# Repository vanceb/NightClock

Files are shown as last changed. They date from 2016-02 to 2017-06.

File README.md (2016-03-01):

# NightClock
This was my first project after joining the [Reading Hackspace](http://rlab.org.uk/).  It exposed me to a number of new techniques and software.

* 2D CAD and laser cutting for the physical clock.  CAD models in dxf format and some cutting files from RDWorks (used by the hackspace laser cutter) are included in the cad folder.
* PCB Design using [Kicad](http://kicad-pcb.org/).  This is the first PCB I have designed.  I had it made in China by [PCBWay](http://www.pcbway.com/).
* Programming the ESP8266 and neopixels for the clock electronics.  I used [Platformio](http://platformio.org/) to program the ESP8266 and manage the libraries.  It uses the core Arduino model for software development, but I prefer it to using the Arduino IDE, which I find frustrating.  I have also used the platformio-ide plugin for [Atom](https://atom.io/), which also works well.

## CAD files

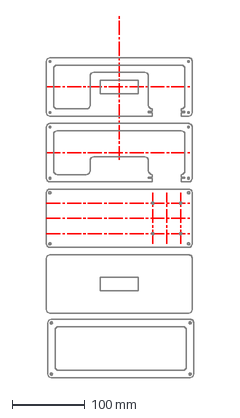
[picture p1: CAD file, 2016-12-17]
cad/NewBase_Wood.dxf
202.0 x 495.3 mm

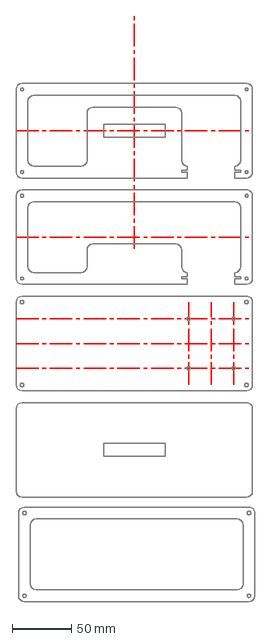
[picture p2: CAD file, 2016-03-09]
cad/NewBase.dxf
202.0 x 495.3 mm

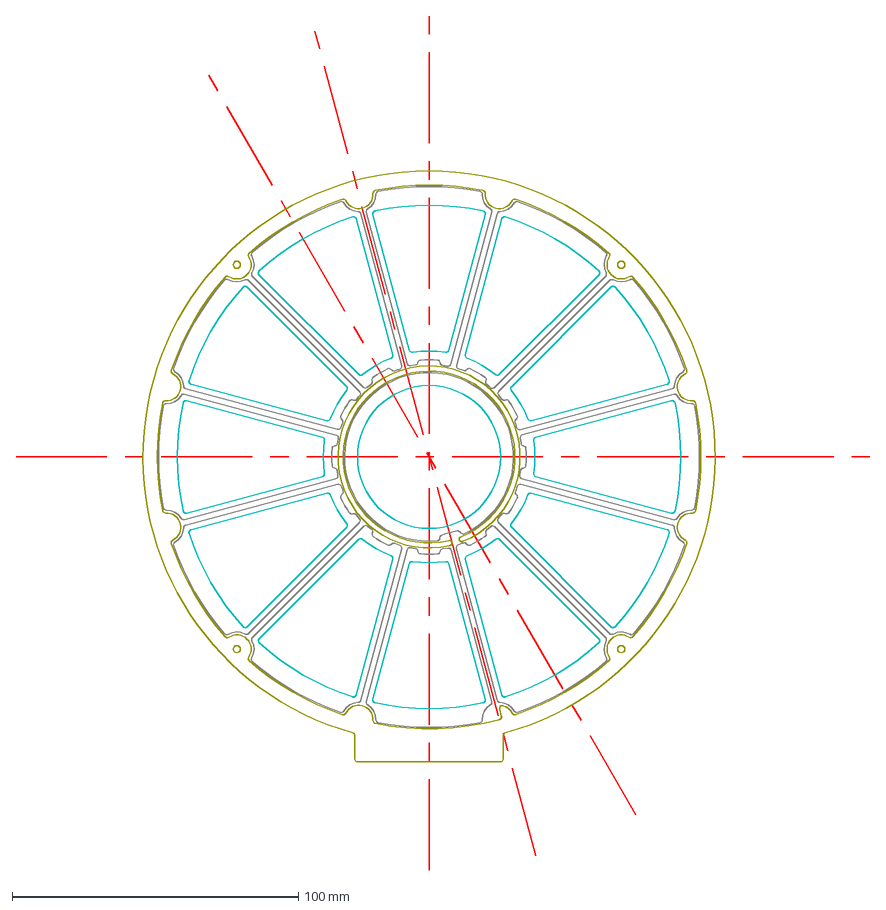
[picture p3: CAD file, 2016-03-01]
cad/Clock.dxf
298.5 x 298.5 mm

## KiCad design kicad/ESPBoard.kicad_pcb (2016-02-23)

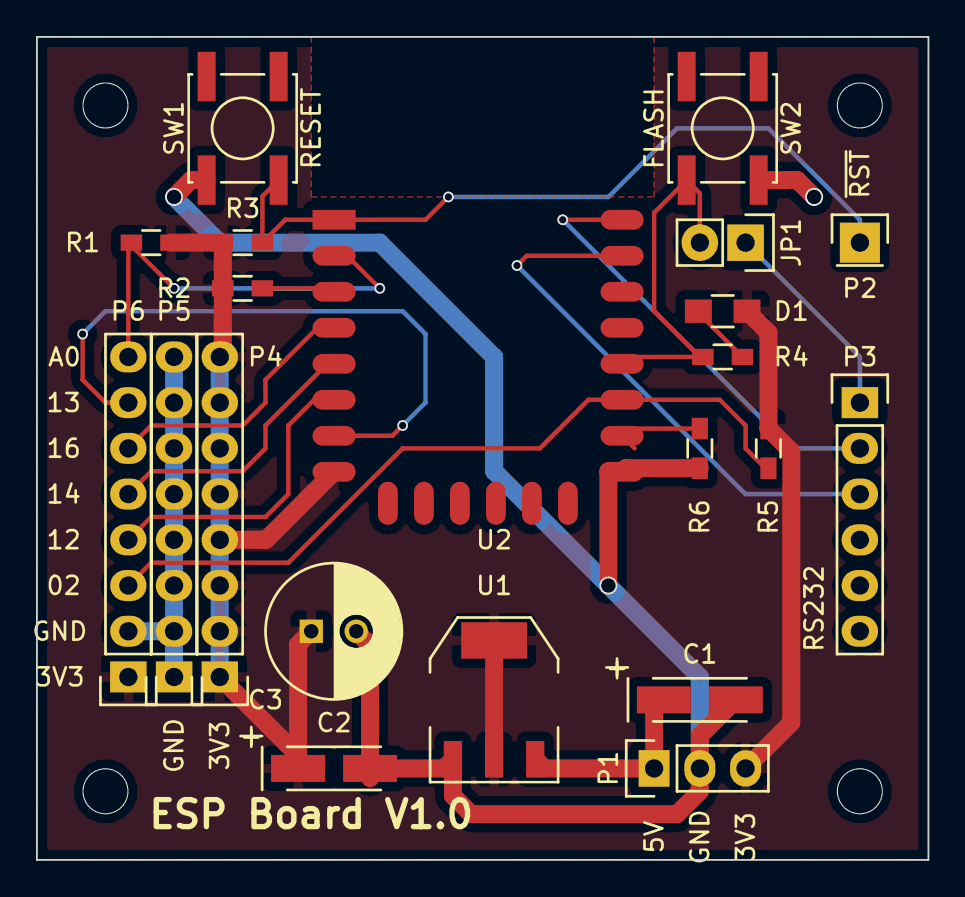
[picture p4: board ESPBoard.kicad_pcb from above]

Board: 2 copper layers, 49.5 x 45.7 mm, 21 parts (0 on the bottom side), 17 nets.

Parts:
C1, C2: 10u; TantalC_SizeA_EIA-3216_HandSoldering
C3: 1000u; C_Radial_D7.5_L11.2_P2.5
D1: LED; R_0805_HandSoldering
JP1: AUTO_FLASH; Pin_Header_Straight_1x02
P1: PWR; Pin_Header_Straight_1x03
P2: EXT_RESET; Pin_Header_Straight_1x01
P3: RS232; Pin_Header_Straight_1x06
P4: 3.3V; Pin_Header_Straight_1x08
P5: Gnd; Pin_Header_Straight_1x08
P6: GPIO; Pin_Header_Straight_1x08
R1: 470k; R_0603_HandSoldering
R2, R3, R5, R6: 10k; R_0603_HandSoldering
R4: 330R; R_0603_HandSoldering
SW1: RESET; SW_SPST_EVPBF
SW2: FLASH; SW_SPST_EVPBF
U1: LM1117-3.3; SOT-223
U2: ESP-12E

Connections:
+3V3: C2.1, C3.1, D1.2, P1.3, P4.1, P4.2, P4.3, P4.4, P4.5, P4.6, P4.7, P4.8, P6.1, R1.1, R2.1, R3.1, R5.1, U1.2, U1.4, U2.8
+5V: C1.1, P1.1, U1.3
/ESP_ADC: P6.8, R1.2, U2.2
/ESP_CH_PD: R2.2, U2.3
/ESP_GPIO0: JP1.2, R4.2, SW2.2, U2.18
/ESP_GPIO2: P6.3, R5.2, U2.17
/ESP_GPIO12: P6.4, U2.6
/ESP_GPIO13: P6.7, U2.7
/ESP_GPIO14: P6.5, U2.5
/ESP_GPIO15: R6.1, U2.16
/ESP_GPIO16: P6.6, U2.4
/ESP_RESET: P2.1, R3.2, SW1.2, U2.1
/ESP_RX_IN: P3.3, U2.21
/ESP_TX_OUT: P3.2, U2.22
/SERIAL_DTR: JP1.1, P3.1
GNDPWR: C1.2, C2.2, C3.2, P1.2, P3.6, P5.1, P5.2, P5.3, P5.4, P5.5, P5.6, P5.7, P5.8, P6.2, R6.2, SW1.1, SW2.1, U1.1, U2.15
unnamed: D1.1, R4.1

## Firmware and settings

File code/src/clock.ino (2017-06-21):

// https://github.com/adafruit/Adafruit_NeoPixel
// Platformio lib number 28
#include <Adafruit_NeoPixel.h>

// https://github.com/PaulStoffregen/Time
// Platformio lib number 28
#include <TimeLib.h>

// Time zone and daylight savings conversion, but cannot be used as-is
// ESP eeprom library not yet ported, so edited library to remove
// requirement on that library
// Original Library
// https://github.com/JChristensen/Timezone
// If it worked OOTB then would be Platformio lib number 76
// Forked version
// https://github.com/vanceb/Timezone
#include <Timezone.h>

// https://github.com/esp8266/arduino
#include <ESP8266WiFi.h>
#include <WiFiUdp.h>

// Use WifiManager to allow easier setting of Wifi
#include <DNSServer.h>
#include <ESP8266WebServer.h>
#include <WiFiManager.h>

// Enable OTA Software updates
#include <ESP8266mDNS.h>
#include <ArduinoOTA.h>

// Define the parameters for the neopixels
#define NEO_PIN 13
#define NEO_NUMPIXELS 13

// Enum and variable to hold the status
enum status {WIFI_UP, WIFI_DOWN, WIFI_CFG, NTP_FAIL};
status clock_status = WIFI_DOWN;

// NTP Servers:
IPAddress timeServerIP; // time.nist.gov NTP server address
const char* ntpServerName = "1.uk.pool.ntp.org";
//IPAddress timeServer(132, 163, 4, 101); // time-a.timefreq.bldrdoc.gov
// IPAddress timeServer(132, 163, 4, 102); // time-b.timefreq.bldrdoc.gov
// IPAddress timeServer(132, 163, 4, 103); // time-c.timefreq.bldrdoc.gov

// Setup timezone and daylight saving correction library
TimeChangeRule ukGMT = {"GMT", Last, Sun, Oct, 2, 0};
TimeChangeRule ukBST = {"BST", Last, Sun, Mar, 2, 60};
Timezone ukTZ(ukGMT, ukBST);

// Create the Neopixel object
Adafruit_NeoPixel strip = Adafruit_NeoPixel(NEO_NUMPIXELS, NEO_PIN, NEO_GRB + NEO_KHZ800);

// To allow for OTA reconfig of colours later on define a set of variables
uint32_t col_wifi_down = strip.Color(128,0,0);
uint32_t col_wifi_up = strip.Color(0,128,0);
uint32_t col_wifi_cfg = strip.Color(0,0,128);
uint32_t col_ntp_fail = strip.Color(64,64,0);
uint32_t col_hours = strip.Color(255,0,0);
uint32_t col_minutes = strip.Color(0,0,255);
uint32_t col_seconds = strip.Color(0,255,0);
uint32_t col_background = strip.Color(0,0,0);

uint8_t show_sec_brightness = 64;
uint8_t min_brightness = 3;
uint8_t max_brightness = 255;
uint32_t last_updated = millis();
uint32_t time_now = millis();
uint8_t disp_update_period = 40;
uint8_t ntp_sync_interval = 3600;

// Manage brightness with hysteresis
#define GO_BRIGHT 600
#define GO_DARK 700
bool isDark = false;

// Some status variables
bool ntp_fail = false;
bool wifi_cfg = false;

// Create the UDP object
WiFiUDP Udp;

unsigned int localPort = 8888;  // local port to listen for UDP packets


void walk(uint32_t c, uint8_t wait){
    for(int i=0; i < strip.numPixels(); i++){
        strip.setPixelColor(i, c);
        strip.show();
        delay(wait);
        strip.setPixelColor(i, 0);
    }
}

void showStatus(){
    if (wifi_cfg) {
        clock_status = WIFI_CFG;
        strip.setPixelColor(12, col_wifi_cfg);
    } else {
        switch (WiFi.status()){
            case WL_CONNECTED :
            if(ntp_fail) {
                clock_status = NTP_FAIL;
                strip.setPixelColor(12, col_ntp_fail);
            } else {
                clock_status = WIFI_UP;
                strip.setPixelColor(12, col_wifi_up);
            }
            break;
            default :
            strip.setPixelColor(12, col_wifi_down);
            clock_status = WIFI_DOWN;
        }
    }
}


void showTime() {
    time_t t = now();
    int hr_seg = (hour(t) + 6) % 12;
    int min_seg = ((minute(t) / 5) + 6) % 12;
    int sec_seg = ((second(t) / 5) + 6) % 12;
    for (int i=0; i<12; i++){
        if (i == hr_seg){
            strip.setPixelColor(i, col_hours);
        }
        if (i == min_seg) {
            strip.setPixelColor(i, mixColors(strip.getPixelColor(i), col_minutes));
        }
        if (i == sec_seg) {
            strip.setPixelColor(i, mixColors(strip.getPixelColor(i), col_seconds));
        }
        if (strip.getPixelColor(i) == 0) {
            strip.setPixelColor(i, col_background);
        }
    }
}


void fadeTime() {
    time_t t = ukTZ.toLocal(now());
    int hr_seg = (hour(t) + 6) % 12;
    int hr_fraction = minute(t);
    int min_seg = ((minute(t) / 5) + 6) % 12;
    int min_fraction = (minute(t) % 5)*60 + second(t);
    int sec_seg = ((second(t) / 5) + 6) % 12;
    int sec_fraction = ((second(t) % 5));
    for (int i=0; i<12; i++){
        if (i == hr_seg){
            strip.setPixelColor(i, fadeColor(col_hours, 60 - hr_fraction, 60));
        }
        if (i == (hr_seg + 1) % 12){
            strip.setPixelColor(i, mixColors(strip.getPixelColor(i), fadeColor(col_hours, hr_fraction, 60)));
        }
        if (i == min_seg) {
            strip.setPixelColor(i, mixColors(strip.getPixelColor(i), fadeColor(col_minutes, 300 - min_fraction, 300)));
        }
        if (i == (min_seg + 1) % 12) {
            strip.setPixelColor(i, mixColors(strip.getPixelColor(i), fadeColor(col_minutes, min_fraction, 300)));
        }
        if (strip.getBrightness() > show_sec_brightness) {
            if (i == sec_seg) {
                strip.setPixelColor(i, mixColors(strip.getPixelColor(i), fadeColor(col_seconds, 5-sec_fraction, 5)));
            }
            if (((i + 11) % 12) == sec_seg) {
                strip.setPixelColor(i, mixColors(strip.getPixelColor(i), fadeColor(col_seconds, sec_fraction, 5)));
            }
        }
        if (strip.getPixelColor(i) == 0) {
            strip.setPixelColor(i, col_background);
        }
    }
}

void ambientLight(){
    /*
    // Read LDR Value
    uint16_t light = analogRead(A0);
    uint8_t brightness = map(light, 0, 1023, 255, 0);
    brightness = constrain(brightness, min_brightness, 255);
    //Set Brightness of the Neopixels
    strip.setBrightness((uint8_t)brightness);
    */
    uint16_t light = analogRead(A0);
    uint8_t brightness;
    if (light > GO_DARK && !isDark) {
        isDark = true;
    } else if (light < GO_BRIGHT && isDark) {
        isDark = false;
    }
    if (isDark) {
        brightness = min_brightness;
    } else {
        brightness = max_brightness;
    }
    strip.setBrightness((uint8_t)brightness);
}

void updateDisplay(){
    ambientLight();
    strip.clear();
    showStatus();
    //    showTime();
    fadeTime();
    strip.show();
}

uint32_t mixColors(uint32_t c1, uint32_t c2) {
    uint8_t
    r1 = (uint8_t)(c1 >> 16),
    g1 = (uint8_t)(c1 >>  8),
    b1 = (uint8_t)c1,
    r2 = (uint8_t)(c2 >> 16),
    g2 = (uint8_t)(c2 >>  8),
    b2 = (uint8_t)c2;

    uint16_t
    r = r1 + r2,
    g = g1 + g2,
    b = b1 + b2;
    if (r > 255) r = 255;
    if (g > 255) g = 255;
    if (b > 255) b = 255;
    /*
    uint8_t
    r = (uint8_t)((r1 + r2) >> 1),
    g = (uint8_t)((g1 + g2) >> 1),
    b = (uint8_t)((b1 + b2) >> 1);
    */

    return strip.Color((uint8_t)r, (uint8_t)g, (uint8_t)b);
}

uint32_t fadeColor(uint32_t c, uint16_t proportion, uint16_t divisor) {
    uint8_t
    r = (uint8_t)(((c >> 16) & 0xFF) * proportion / divisor),
    g = (uint8_t)(((c >> 8) & 0xFF) * proportion / divisor),
    b = (uint8_t)((c & 0xFF) * proportion / divisor);
    return strip.Color(r,g,b);
}

/*
uint32_t mixColors(uint32_t c1, uint32_t c2, uint32_t c3) {
uint32_t part = mixColors(c1, c2);
return mixColors(part, c3);
}
*/

/*-------- NTP code ----------*/

const int NTP_PACKET_SIZE = 48; // NTP time is in the first 48 bytes of message
byte packetBuffer[NTP_PACKET_SIZE]; //buffer to hold incoming & outgoing packets


time_t getNtpTime()
{
    while (Udp.parsePacket() > 0) ; // discard any previously received packets
    //get a random server from the pool
    WiFi.hostByName(ntpServerName, timeServerIP);
    Serial.println("Transmit NTP Request");
    sendNTPpacket(timeServerIP);
    uint32_t beginWait = millis();
    while (millis() - beginWait < 1500) {
        int size = Udp.parsePacket();
        if (size >= NTP_PACKET_SIZE) {
            Serial.println("Receive NTP Response");
            Udp.read(packetBuffer, NTP_PACKET_SIZE);  // read packet into the buffer
            unsigned long secsSince1900;
            // convert four bytes starting at location 40 to a long integer
            secsSince1900 =  (unsigned long)packetBuffer[40] << 24;
            secsSince1900 |= (unsigned long)packetBuffer[41] << 16;
            secsSince1900 |= (unsigned long)packetBuffer[42] << 8;
            secsSince1900 |= (unsigned long)packetBuffer[43];
            ntp_fail = false;
            return secsSince1900 - 2208988800UL;
        }
    }
    ntp_fail = true;
    return 0; // return 0 if unable to get the time
}


// send an NTP request to the time server at the given address
void sendNTPpacket(IPAddress &address)
{
    // set all bytes in the buffer to 0
    memset(packetBuffer, 0, NTP_PACKET_SIZE);
    // Initialize values needed to form NTP request
    // (see URL above for details on the packets)
    packetBuffer[0] = 0b11100011;   // LI, Version, Mode
    packetBuffer[1] = 0;     // Stratum, or type of clock
    packetBuffer[2] = 6;     // Polling Interval
    packetBuffer[3] = 0xEC;  // Peer Clock Precision
    // 8 bytes of zero for Root Delay & Root Dispersion
    packetBuffer[12]  = 49;
    packetBuffer[13]  = 0x4E;
    packetBuffer[14]  = 49;
    packetBuffer[15]  = 52;
    // all NTP fields have been given values, now
    // you can send a packet requesting a timestamp:
    Udp.beginPacket(address, 123); //NTP requests are to port 123
    Udp.write(packetBuffer, NTP_PACKET_SIZE);
    Udp.endPacket();
}


void setup() {
    // Use Serial for debugging
    Serial.begin(115200);
    Serial.println("Booting");

    // Setup ADC Input pin
    pinMode(A0, INPUT);
    // Neopixels Setup
    strip.begin();
    ambientLight();
    // Startup Sequence
    walk(strip.Color(255,0,150), 160);
    strip.clear();
    // Wifi start
    WiFiManager wifiManager;
    wifiManager.setDebugOutput(false);
    // Set timeout to exit the config portal after 3 minutes
    wifiManager.setConfigPortalTimeout(180);

    // Set status to wifi_cfg
    wifi_cfg = true;
    // Show wifi status
    showStatus();
    strip.show();

    // Loop around until we get wifi connectivity
    while (WiFi.status() != WL_CONNECTED) {
        // Try to autoconnect to last wifi network
        // If this fails then open the config portal for 3 minutes
        wifiManager.autoConnect("VB-CLOCK", "vb-clock");
    }

    // Set status to wifi_cfg
    wifi_cfg = false;
    // Show wifi status
    showStatus();
    strip.show();

    // Initialise NTP stuff
    Udp.begin(localPort);
    // This regularly checks NTP to update the time
    // Set the sync interval to 15 seconds until we manage to set the time
    setSyncInterval(15);
    setSyncProvider(getNtpTime);
    while(timeStatus() == timeNotSet){
        showStatus();
        delay(disp_update_period);
    }
    last_updated = millis();
    // Set the sync interval to something more reasonable
    setSyncInterval(ntp_sync_interval);

    // Include some sueful debugging feedback for the OTA programming
    ArduinoOTA.onStart([]() {
        Serial.println("OTA Start");
    });
    ArduinoOTA.onEnd([]() {
        Serial.println("OTA End");
    });
    ArduinoOTA.onProgress([](unsigned int progress, unsigned int total) {
        Serial.printf("Progress: %u%%\n", (progress / (total / 100)));
    });
    ArduinoOTA.onError([](ota_error_t error) {
        Serial.printf("Error[%u]: ", error);
        if (error == OTA_AUTH_ERROR) Serial.println("Auth Failed");
        else if (error == OTA_BEGIN_ERROR) Serial.println("Begin Failed");
        else if (error == OTA_CONNECT_ERROR) Serial.println("Connect Failed");
        else if (error == OTA_RECEIVE_ERROR) Serial.println("Receive Failed");
        else if (error == OTA_END_ERROR) Serial.println("End Failed");
    });
    // Kick-off the OTA update code
    ArduinoOTA.setHostname("vb-clock");
    //ArduinoOTA.setPassword((const char *)"vb-clock");
    ArduinoOTA.begin();
    Serial.println("Ready");
    Serial.print("IP address: ");
    Serial.println(WiFi.localIP());
}

void loop() {
    time_now = millis();
    if(last_updated + disp_update_period < time_now) {
        last_updated = time_now;
        updateDisplay();
    }
    ArduinoOTA.handle();
    yield();
}

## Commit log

2016-01-17 Initial commit of work in progress pulled together into a single entity
    [Clock.dxf]
2016-01-18 Corrected an issue with colour combining when fading the seconds
    [clock.ino]
2016-01-26 Updated cad drawings and broke out credentials files
    [Clock.dxf, Clock_Cutting.dxf]
2016-01-26 Removed obsolete cad files and added cutting files for RDWorks - Laser Cutter
    [Clock.dxf, Clock_Cutting.dxf]
2016-01-28 Updated colour mixing function to improve brightness issues
    [clock.ino]
2016-02-01 Created ESP Board first version
    [ESPBoard.kicad_pcb, ESPBoard.sch]
2016-02-10 Updated board and produced Gerbers
    [ESPBoard-B.Cu.gbl, ESPBoard-B.Mask.gbs, ESPBoard-B.SilkS.gbo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]
2016-02-11 Removed test BOM files
2016-02-12 Updated schematic and laid out PCB components so max dimension is less than 50mm. Tracks still need to be connected
    [ESPBoard-B.Cu.gbl, ESPBoard-B.Mask.gbs, ESPBoard-B.SilkS.gbo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]
2016-02-12 Routed the board
    [ESPBoard.kicad_pcb]
2016-02-23 PCB Sent for manufacture
    [ESPBoard.kicad_pcb]
2016-02-23 Gerber files
    [ESPBoard-B.Cu.gbl, ESPBoard-B.Mask.gbs, ESPBoard-B.SilkS.gbo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]
2016-02-24 Some additional cad drawings used to create the new base
    [BaseTopBottom.dxf, BaseTopBottomQCAD.dxf, BaseTopBottomR14.dxf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]
2016-03-01 Updated drawings and included the rld cut files for the Reading Hackspace Laser Cutter
    [BaseTopBottomQCAD.dxf, Clock.dxf, Clock_cut_10mm_black.dxf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]
2016-03-01 tidying a backup file
    [~BaseTopBottomQCAD.dxf]
2016-03-01 Tidied CAD files
    [BaseTopBottom.dxf, BaseTopBottomR14.dxf, Clock.dxf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]
2016-03-09 commit prior to branching for OTA Upgrades
    [NewBase.dxf]
2016-03-28 Updated to allow correction of daylight saving time, including modification of the Timezone library to remove eeprom code
    [clock.ino]
2016-12-17 Wooden clock code and CAD
    [NewBase_Wood.dxf]
